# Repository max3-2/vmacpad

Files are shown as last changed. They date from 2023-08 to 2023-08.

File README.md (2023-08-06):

# vmacpad

A custom macro pad especially suited for FCPX and any other thing that needs
scrolling!

## ToDos from an old project

- Improve GND on PCB for controller. Not needed since it works really good but
better practice
- Improve plate manufacture or / and increase switch opening size. The current
dimensioning is ok but fairly tight.
- Do the same for the stabs, if possible add at least 1mm left / right for the
stems

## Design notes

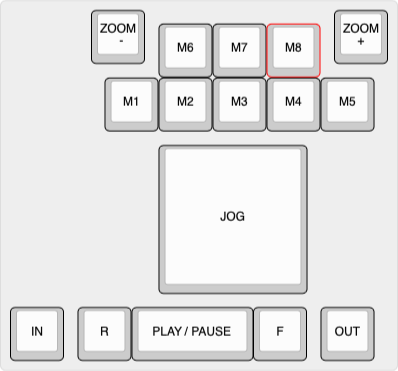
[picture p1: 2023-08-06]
layout/vmacpad.png

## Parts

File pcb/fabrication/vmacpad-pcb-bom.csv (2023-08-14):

Comment | Designator | Footprint | LCSC
22u | C1,C2 | Capacitor_SMD:C_1206_3216Metric | C2858005
10u | C10,C17 | Capacitor_SMD:C_0805_2012Metric | C88484
4.7u | C11,C13 | Capacitor_SMD:C_0402_1005Metric | C368809
10n | C14 | Capacitor_SMD:C_0402_1005Metric | C60133
10p | C15,C16 | Capacitor_SMD:C_0402_1005Metric | C115606
22n | C18,C19 | Capacitor_SMD:C_0805_2012Metric | C51574
100n | C3,C4,C5,C6,C7,C8,C9,C12 | Capacitor_SMD:C_0402_1005Metric | C77020
SM4007 | D1,D2,D4,D5,D6,D8,D9,D10,D11,D12,D13,D14,D16,D17,D18,D20 | Diode_SMD:D_SOD-123F | C64898
SMF9.0CA | DP1 | Acheron_Components:D_SOD-123_Bidirectional | C123799
ASMD1206-150 | F1 | Fuse:Fuse_1206_3216Metric | C883134
TYPE-C-31-M12_13 | J1 | Acheron_Connectors:TYPE-C-31-M-12 | C165948
60R@100MHz | L1 | Inductor_SMD:L_1206_3216Metric | C33600
5.1k | R1,R2 | Resistor_SMD:R_0805_2012Metric | C144526
10k | R3,R4 | Resistor_SMD:R_0805_2012Metric | C84376
10k | R7 | Resistor_SMD:R_0402_1005Metric | C60490
SW_BOOT | SW1 | Button_Switch_SMD:SW_SPDT_PCM12 | C431540
TPD4E05U06DQAR | U1 | Package_SON:USON-10_2.5x1.0mm_P0.5mm | C138714
TXS0101DBVR | U2 | Acheron_Components:SOT-23-6 | C132604
STM32F401RCTx | U3 | Package_QFP:LQFP-64_10x10mm_P0.5mm | C74524
AMS1117-3.3 | U4 | Package_TO_SOT_SMD:SOT-223-3_TabPin2 | C6186
16MHz | Y1 | Crystal:Crystal_SMD_3225-4Pin_3.2x2.5mm | C112972

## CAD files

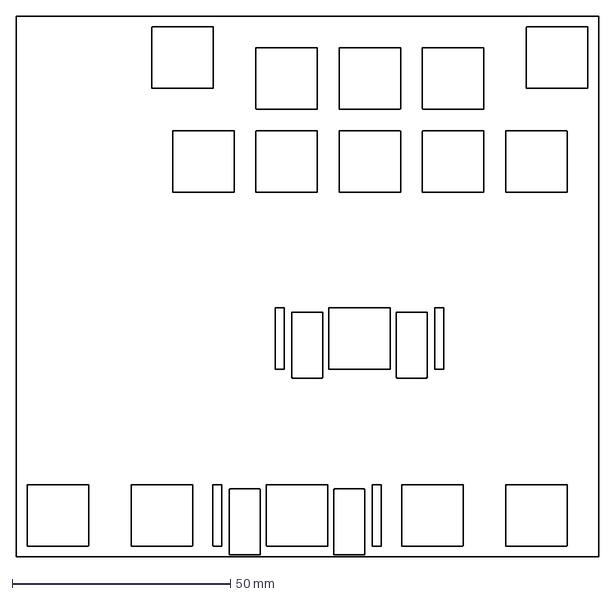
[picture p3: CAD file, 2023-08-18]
case_plate/plate.dxf
133.3 x 123.8 mm

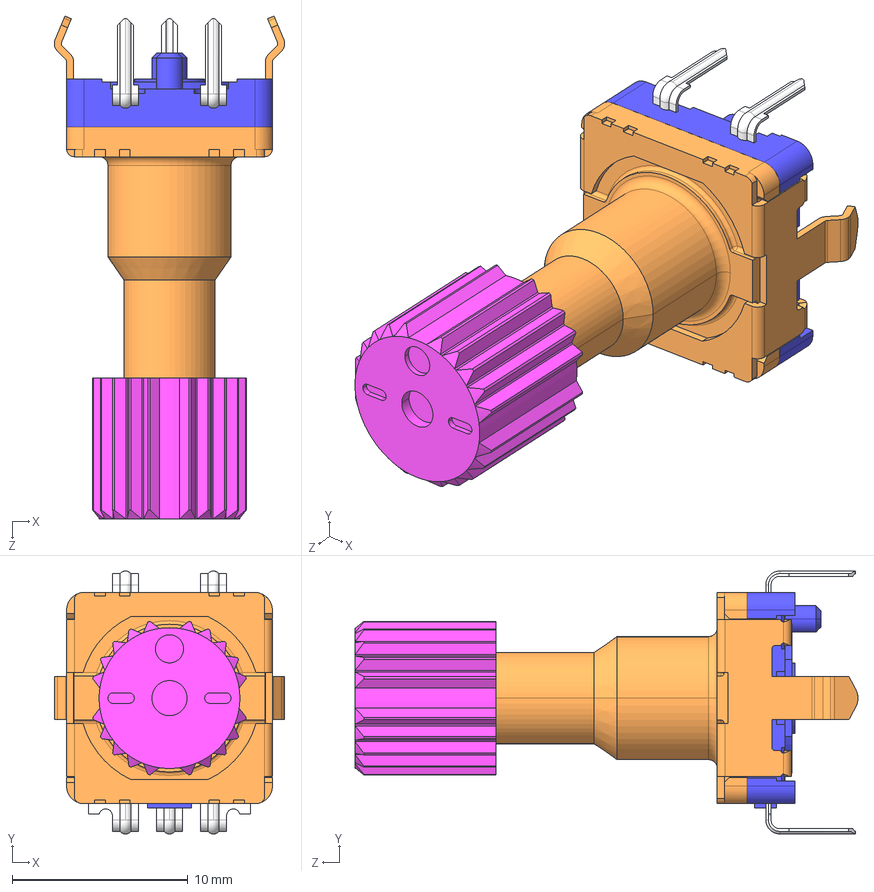
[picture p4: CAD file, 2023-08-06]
pcb/3dmodels/EC11M1565403/EC11M1565403.STEP
13.1 x 15.0 x 28.6 mm

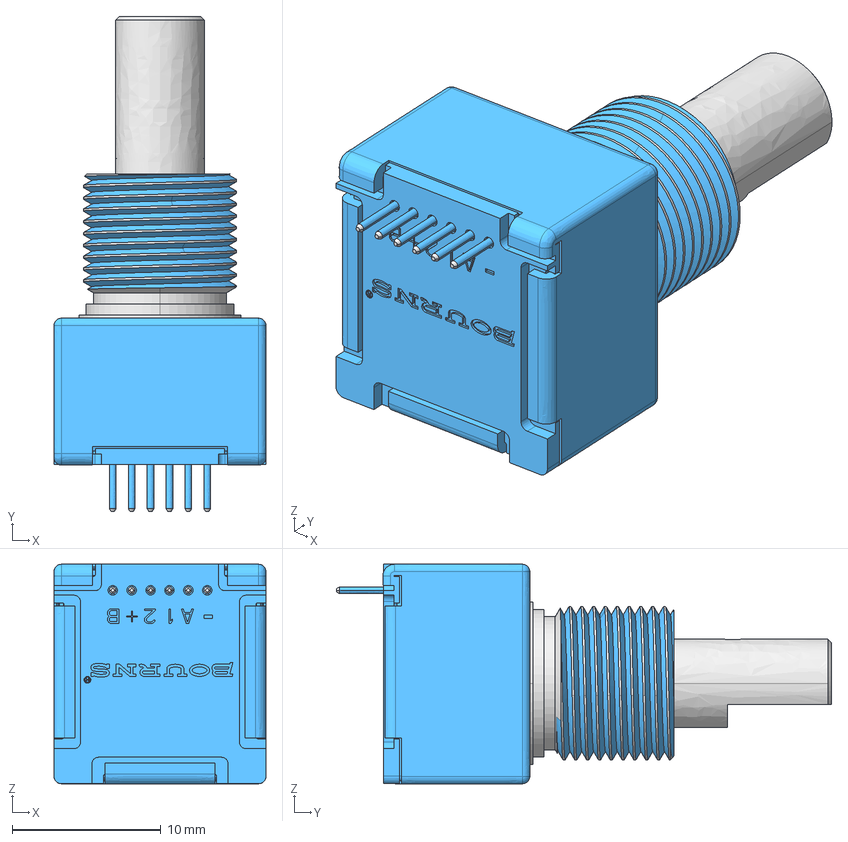
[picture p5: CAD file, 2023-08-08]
pcb/3dmodels/EM14RXD-M20-L.stp
14.2 x 33.3 x 14.8 mm

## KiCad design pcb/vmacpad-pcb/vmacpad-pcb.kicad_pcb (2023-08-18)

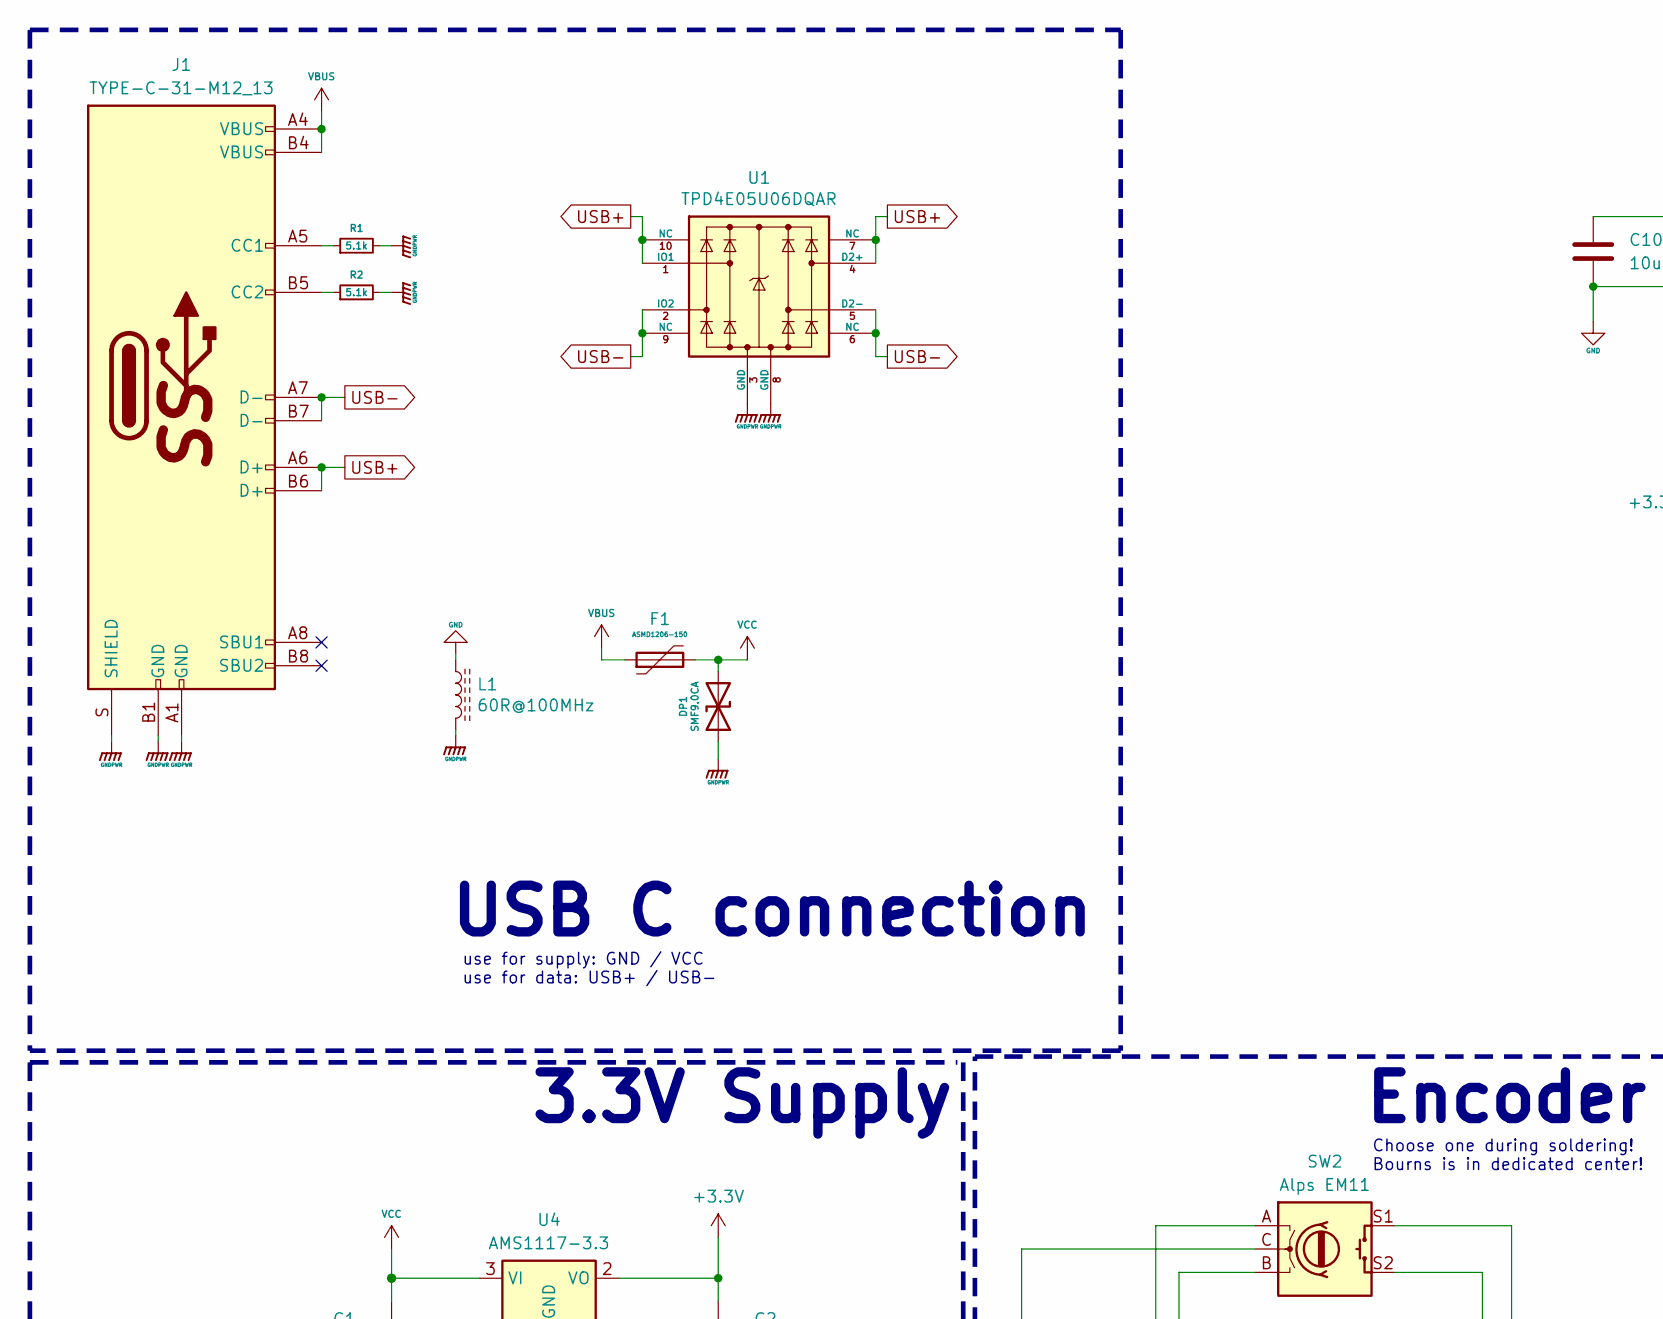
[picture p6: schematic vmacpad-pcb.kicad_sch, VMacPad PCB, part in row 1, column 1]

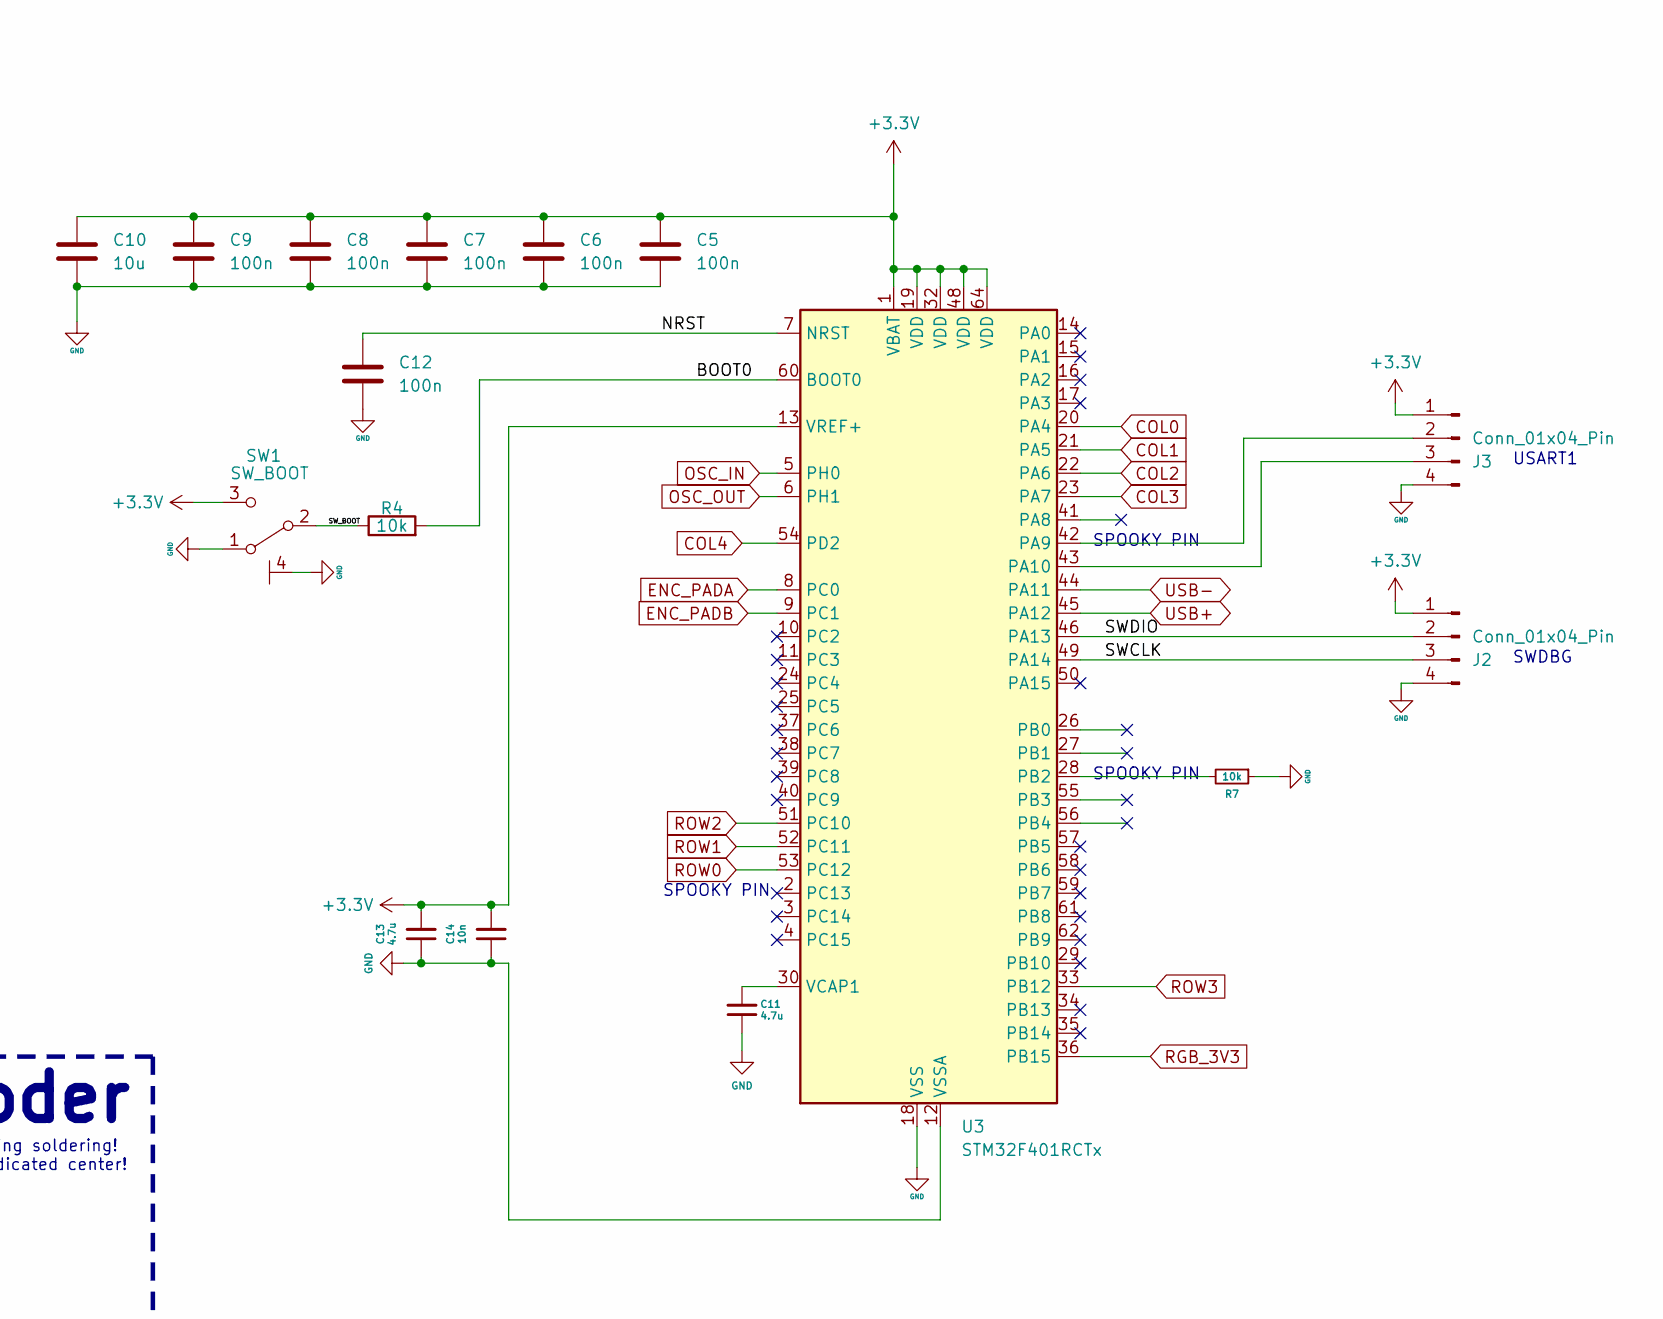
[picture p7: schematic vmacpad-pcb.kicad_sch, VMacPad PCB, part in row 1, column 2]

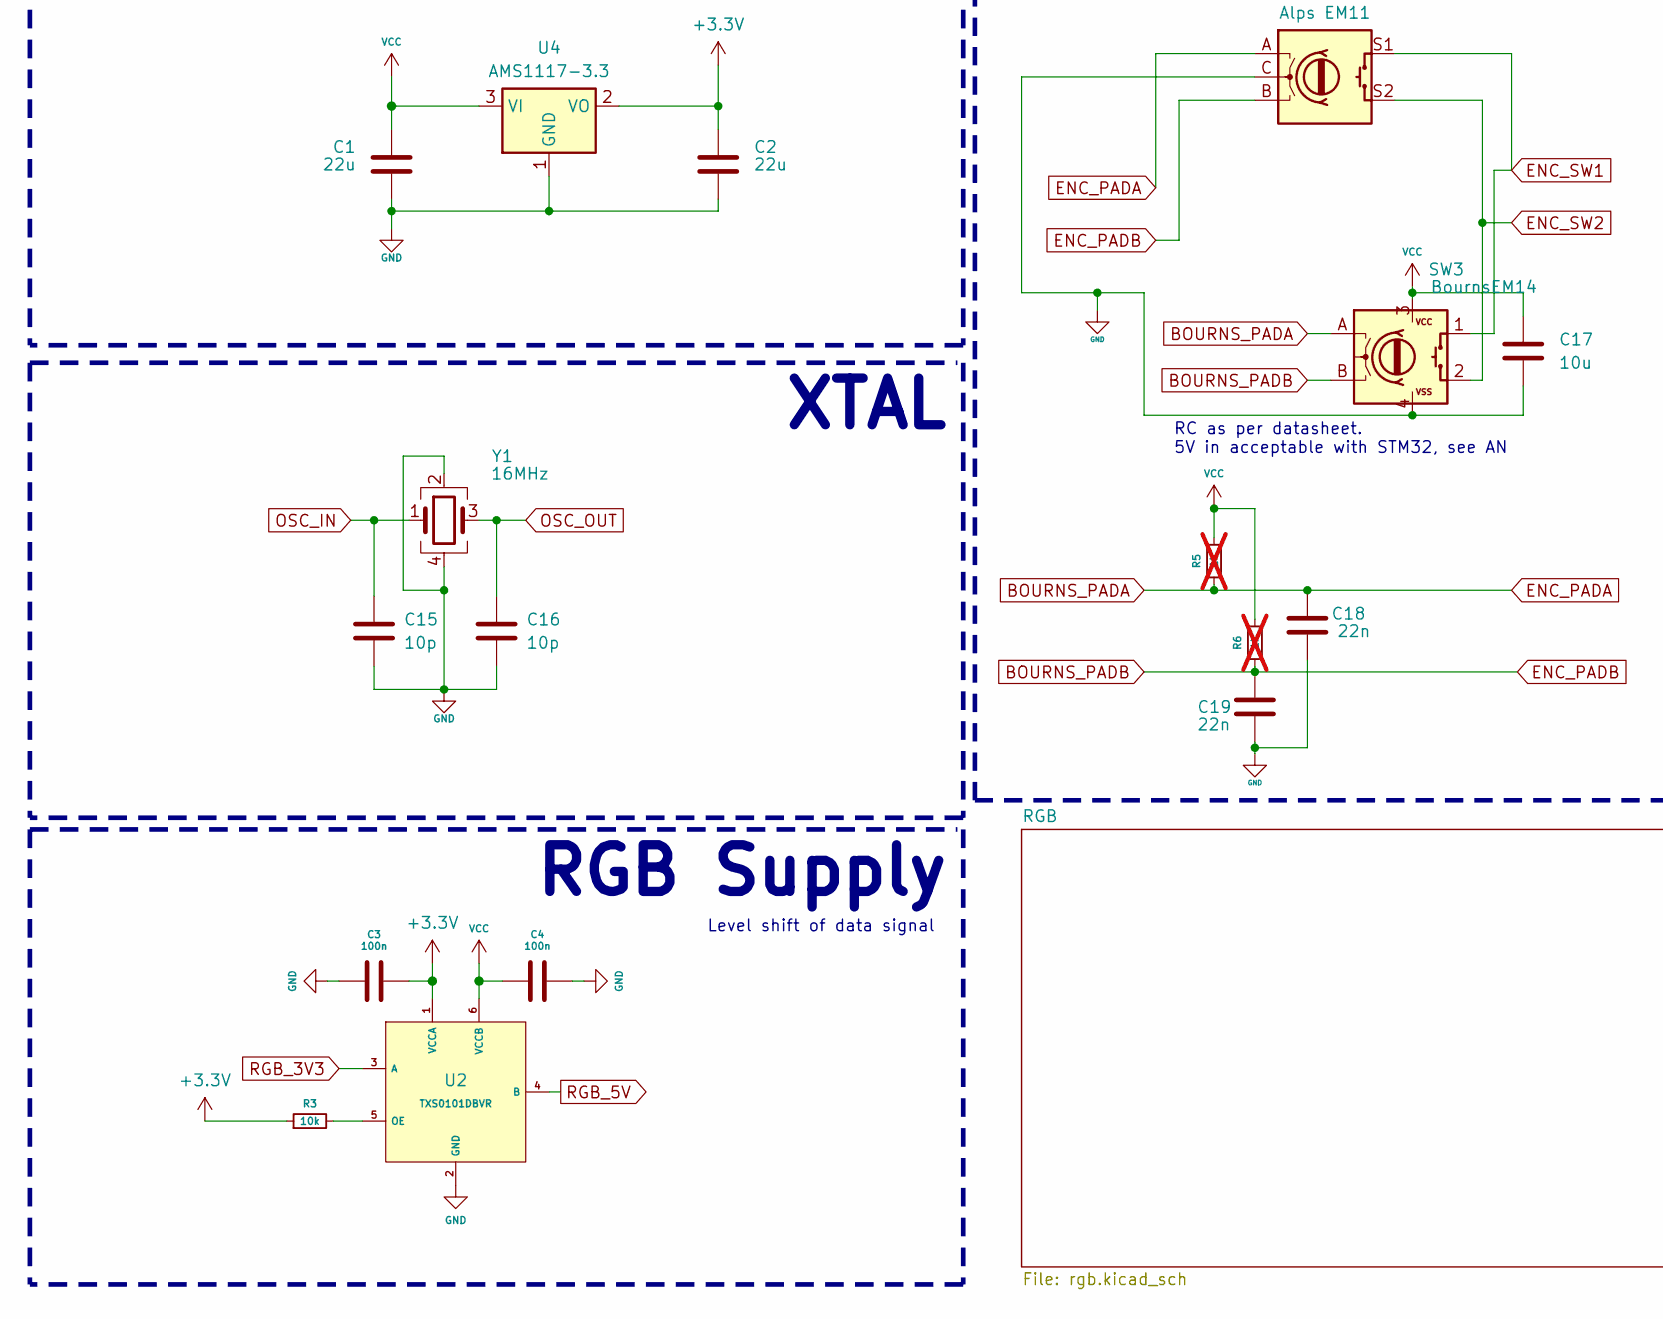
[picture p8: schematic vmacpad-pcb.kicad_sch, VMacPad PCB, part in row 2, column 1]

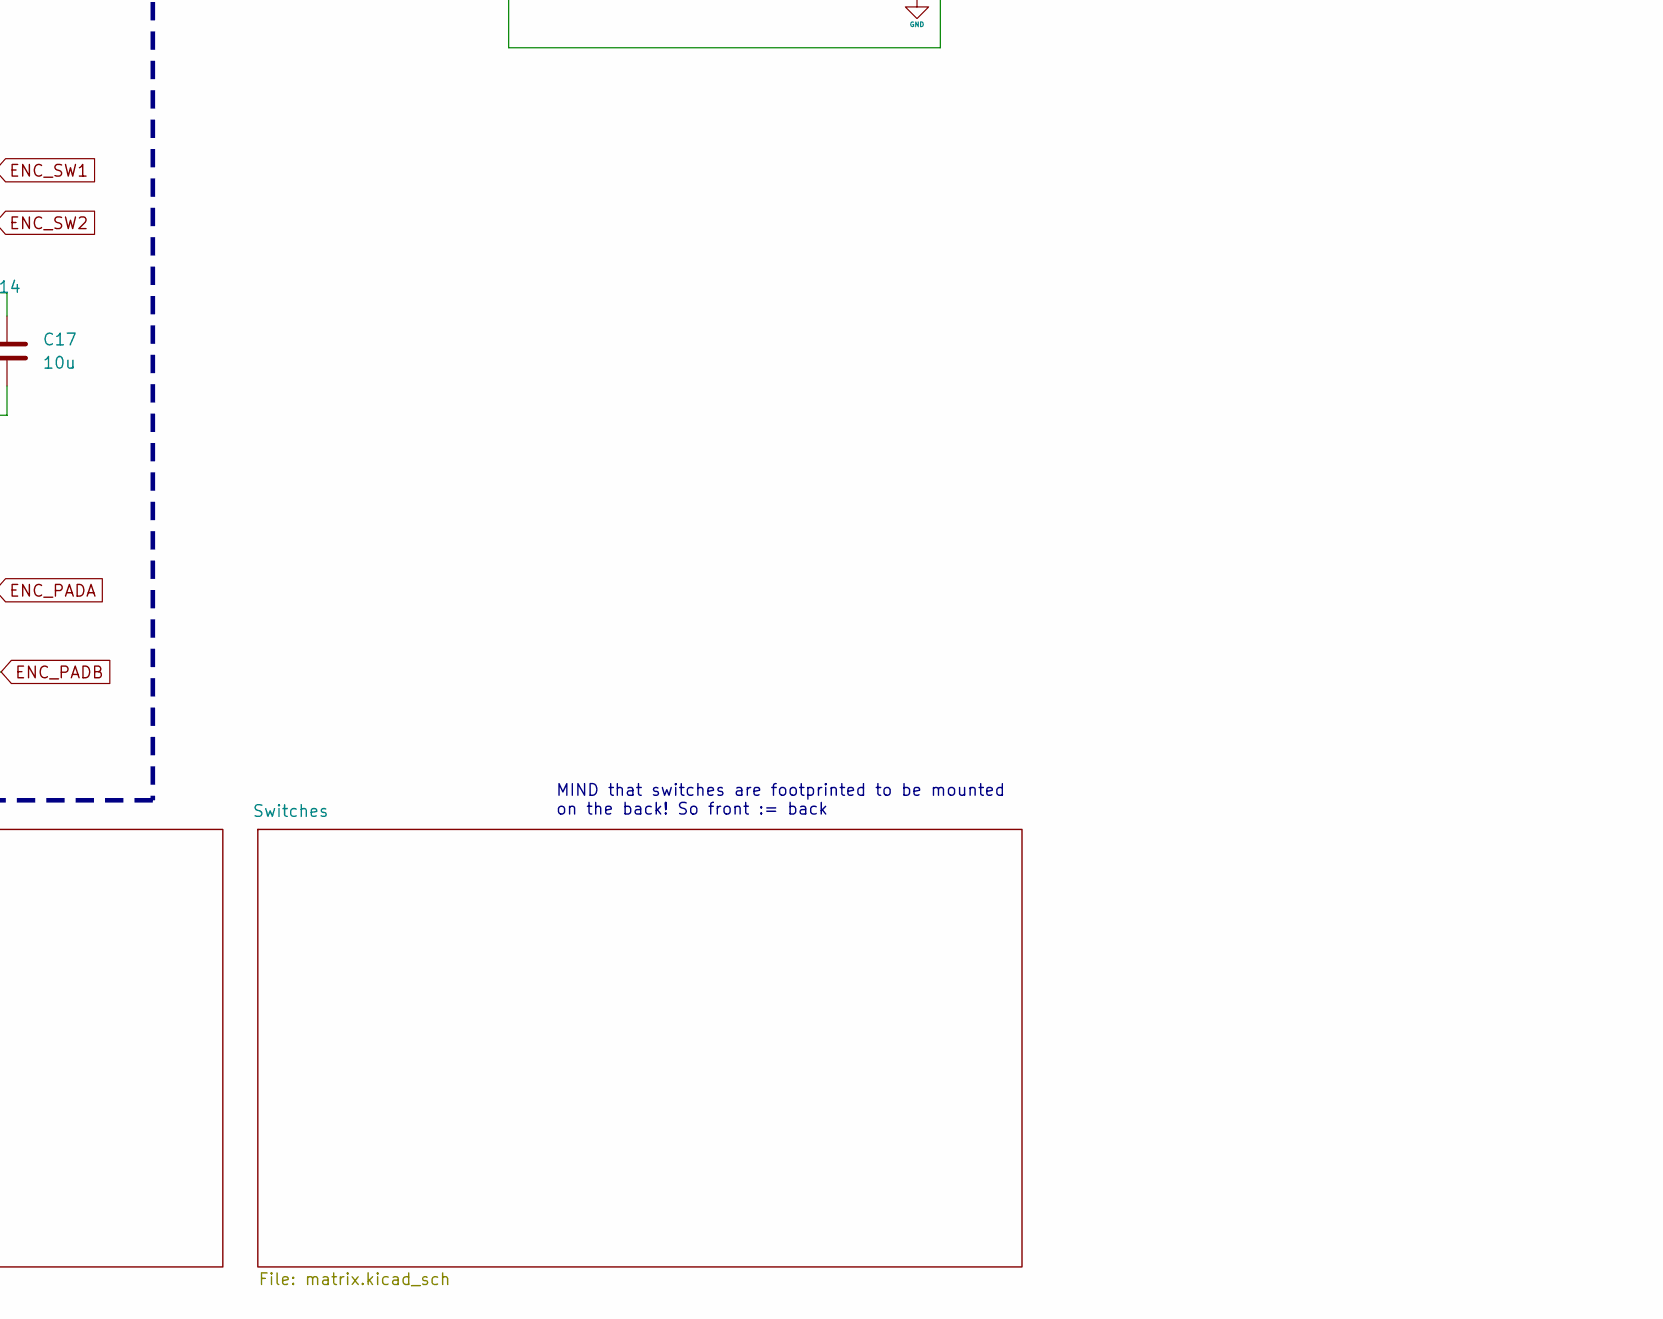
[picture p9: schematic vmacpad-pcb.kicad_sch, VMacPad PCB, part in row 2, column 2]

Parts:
C1, C2: 22u; C_1206_3216Metric; LCSC Part No C2858005
C3, C4, C5, C6, C7, C8, C9, C12: 100n; C_0402_1005Metric; LCSC Part No C77020
C10, C17: 10u; C_0805_2012Metric; LCSC Part No C88484
C11, C13: 4.7u; C_0402_1005Metric; LCSC Part No C368809
C14: 10n; C_0402_1005Metric; LCSC Part No C60133
C15, C16: 10p; C_0402_1005Metric; LCSC Part No C115606
C18, C19: 22n; C_0805_2012Metric; LCSC Part No C51574
DP1: SMF9.0CA; D_SOD-123_Bidirectional; Manufacturer Part No SMF9.0CA; LCSC Part No C123799
F1: ASMD1206-150; Fuse_1206_3216Metric; Manufacturer Part No ASMD1206-150; LCSC Part No C883134
J1: TYPE-C-31-M12_13; TYPE-C-31-M-12; Manufacturer Part No TYPE-C-31-M-12; LCSC Part No C165948
J2, J3: Conn_01x04_Pin; PinHeader_1x04_P2.54mm_Vertical
L1: 60R@100MHz; L_1206_3216Metric; Manufacturer Part No MLB3216-600P4A(f); LCSC Part No C33600
R1, R2: 5.1k; R_0805_2012Metric; LCSC Part No C144526
R3, R4: 10k; R_0805_2012Metric; LCSC Part No C84376
R5, R6: 1k; R_0805_2012Metric; LCSC Part No C115316; not fitted
R7: 10k; R_0402_1005Metric; LCSC Part No C60490
SW1: SW_BOOT; SW_SPDT_PCM12; LCSC Part No C431540
SW2: Alps EM11; RotaryEncoder_Alps_EC11E-Switch_Vertical_H20mm
SW3: BournsEM14
U1: TPD4E05U06DQAR; USON-10_2.5x1.0mm_P0.5mm; Manufacturer Part No TPD4E05U06DQAR; LCSC Part No C138714
U2: TXS0101DBVR; SOT-23-6; Manufacturer Part Number TXS0101DBVR; LCSC Part No C132604
U3: STM32F401RCTx; LQFP-64_10x10mm_P0.5mm; LCSC Part No C74524
U4: AMS1117-3.3; SOT-223-3_TabPin2; LCSC Part No C6186
Y1: 16MHz; Crystal_SMD_3225-4Pin_3.2x2.5mm; LCSC Part No C112972

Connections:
+3.3V: C2.1, C3.2, C5.1, C6.1, C7.1, C8.1, C9.1, C10.1, C13.2, C14.2, J2.1, J3.1, R3.1, SW1.3 (C), U2.1 (VCCA), U3.1 (VBAT), U3.13 (VREF+), U3.19 (VDD), U3.32 (VDD), U3.48 (VDD), U3.64 (VDD), U4.2 (VO)
/BOOT0: R4.2, U3.60 (BOOT0)
/NRST: C12.1, U3.7 (NRST)
/SWCLK: J2.3, U3.49 (PA14)
/SWDIO: J2.2, U3.46 (PA13)
/SW_BOOT: R4.1, SW1.2 (B)
BOURNS_PADA: C18.1, R5.1, SW2.A, SW3.A, U3.8 (PC0)
BOURNS_PADB: C19.1, R6.1, SW2.B, SW3.B, U3.9 (PC1)
COL0: U3.20 (PA4); also elsewhere on the board
COL1: U3.21 (PA5); also elsewhere on the board
COL2: SW2.S2, SW3.2, U3.22 (PA6); also elsewhere on the board
COL3: U3.23 (PA7); also elsewhere on the board
COL4: U3.54 (PD2); also elsewhere on the board
ENC_SW1: SW2.S1, SW3.1; also elsewhere on the board
GND: C1.2, C2.2, C3.1, C4.2, C5.2, C6.2, C7.2, C8.2, C9.2, C10.2, C11.1, C12.2, C13.1, C14.1, C15.2, C16.2, C17.2, C18.2, C19.2, J2.4, J3.4, L1.1, R7.1, SW1.1 (A), SW1.4 (Fix), SW2.C, SW3.4 (VSS), U2.2 (GND), U3.12 (VSSA), U3.18 (VSS), U3.31 (VSS), U3.47 (VSS), U3.63 (VSS), U4.1 (GND), Y1.2, Y1.4; also elsewhere on the board
GNDPWR: DP1.1 (A1), J1.A1 (GND), J1.B1 (GND), J1.S (SHIELD), L1.2, R1.2, R2.2, U1.3 (GND), U1.8 (GND)
unnamed: J1.A5 (CC1), R1.1
unnamed: J1.B5 (CC2), R2.1
unnamed: J3.2, U3.42 (PA9)
unnamed: J3.3, U3.43 (PA10)
unnamed: R3.2, U2.5 (OE)
unnamed: R7.2, U3.28 (PB2)
unnamed: C11.2, U3.30 (VCAP1)
OSC_IN: C15.1, U3.5 (PH0), Y1.1
OSC_OUT: C16.1, U3.6 (PH1), Y1.3
RGB_3V3: U2.3 (A), U3.36 (PB15)
RGB_5V: U2.4 (B); also elsewhere on the board
ROW0: U3.53 (PC12); also elsewhere on the board
ROW1: U3.52 (PC11); also elsewhere on the board
ROW2: U3.51 (PC10); also elsewhere on the board
ROW3: U3.33 (PB12); also elsewhere on the board
USB+: J1.A6 (D+), J1.B6 (D+), U1.1 (IO1), U1.4 (D2+), U1.7 (NC), U1.10 (NC), U3.45 (PA12)
USB-: J1.A7 (D-), J1.B7 (D-), U1.2 (IO2), U1.5 (D2-), U1.6 (NC), U1.9 (NC), U3.44 (PA11)
VBUS: F1.1, J1.A4 (VBUS), J1.B4 (VBUS)
VCC: C1.1, C4.1, C17.1, DP1.2 (A2), F1.2, R5.2, R6.2, SW3.3 (VCC), U2.6 (VCCB), U4.3 (VI); also elsewhere on the board

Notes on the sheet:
use for supply: GND / VCC use for data: USB+ / USB-
SWDBG
USART1
XTAL
Level shift of data signal
Choose one during soldering! Bourns is in dedicated center!
RGB Supply
RC as per datasheet. 5V in acceptable with STM32, see AN
Encoder
SPOOKY PIN
USB C connection
MIND that switches are footprinted to be mounted on the back! So front := back
3.3V Supply

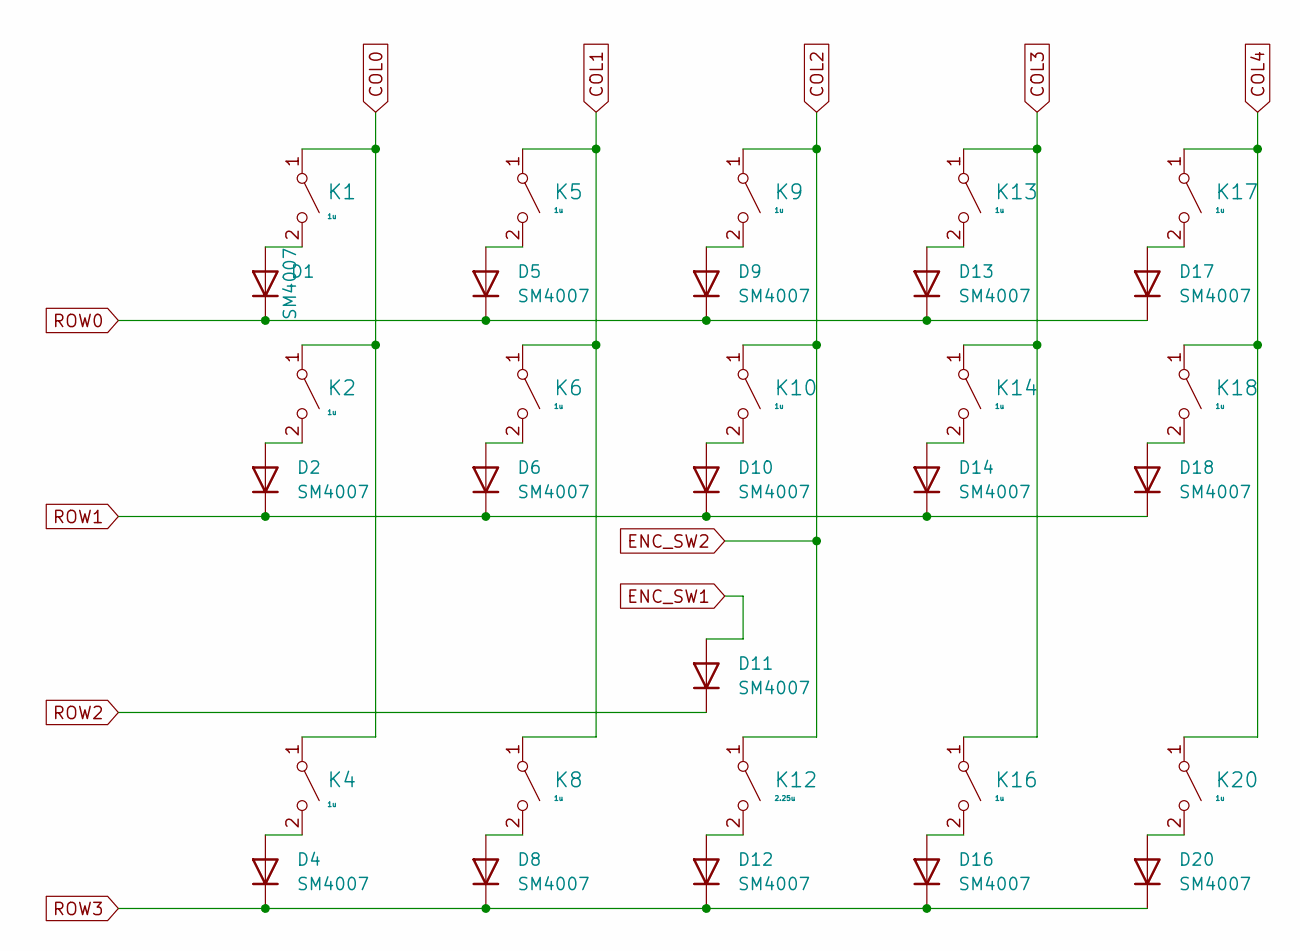
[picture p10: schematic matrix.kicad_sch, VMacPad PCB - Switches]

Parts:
D1, D2, D4, D5, D6, D8, D9, D10, D11, D12, D13, D14, D16, D17, D18, D20: SM4007; D_SOD-123F; LCSC Part No C64898
K1, K2, K4, K5, K6, K8, K9, K10, K13, K14, K16, K17, K18, K20: 1u; MX100H; LCSC Part No C5156480
K12: 2.25u; MX225HR; LCSC Part No C5156480

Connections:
COL0: K1.1 (A), K2.1 (A), K4.1 (A); also elsewhere on the board
COL1: K5.1 (A), K6.1 (A), K8.1 (A); also elsewhere on the board
COL2: K9.1 (A), K10.1 (A), K12.1 (A); also elsewhere on the board
COL3: K13.1 (A), K14.1 (A), K16.1 (A); also elsewhere on the board
COL4: K17.1 (A), K18.1 (A), K20.1 (A); also elsewhere on the board
ENC_SW1: D11.2 (A); also elsewhere on the board
unnamed: D1.2 (A), K1.2 (B)
unnamed: D2.2 (A), K2.2 (B)
unnamed: D4.2 (A), K4.2 (B)
unnamed: D5.2 (A), K5.2 (B)
unnamed: D6.2 (A), K6.2 (B)
unnamed: D8.2 (A), K8.2 (B)
unnamed: D9.2 (A), K9.2 (B)
unnamed: D10.2 (A), K10.2 (B)
unnamed: D12.2 (A), K12.2 (B)
unnamed: D13.2 (A), K13.2 (B)
unnamed: D14.2 (A), K14.2 (B)
unnamed: D16.2 (A), K16.2 (B)
unnamed: D17.2 (A), K17.2 (B)
unnamed: D18.2 (A), K18.2 (B)
unnamed: D20.2 (A), K20.2 (B)
ROW0: D1.1 (K), D5.1 (K), D9.1 (K), D13.1 (K), D17.1 (K); also elsewhere on the board
ROW1: D2.1 (K), D6.1 (K), D10.1 (K), D14.1 (K), D18.1 (K); also elsewhere on the board
ROW2: D11.1 (K); also elsewhere on the board
ROW3: D4.1 (K), D8.1 (K), D12.1 (K), D16.1 (K), D20.1 (K); also elsewhere on the board

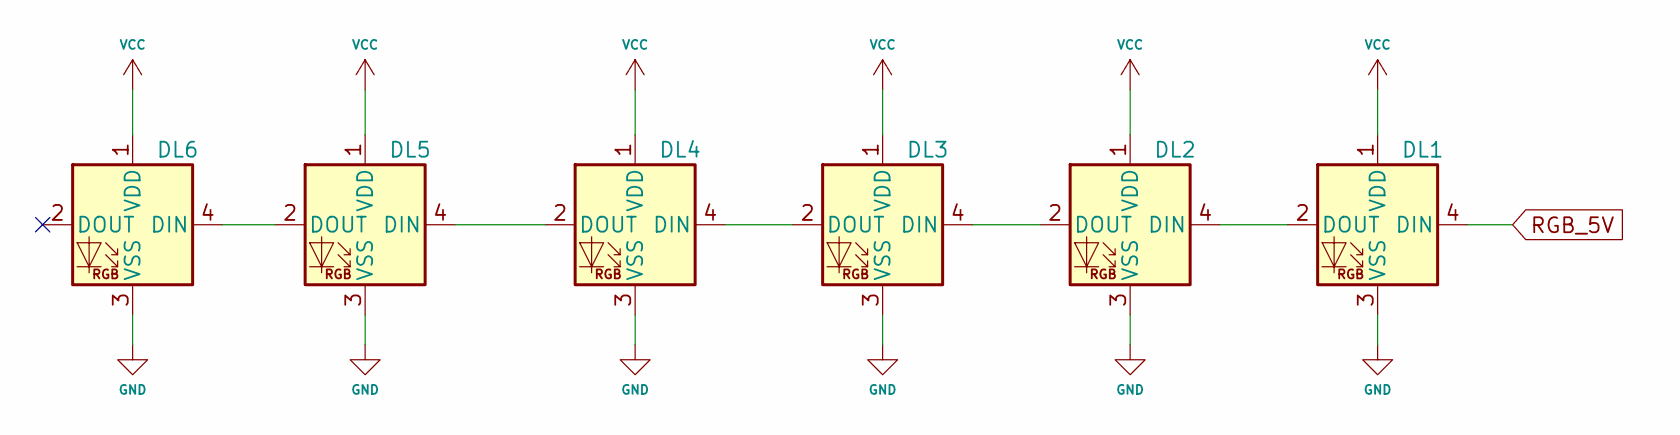
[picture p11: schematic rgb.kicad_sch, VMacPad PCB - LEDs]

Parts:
DL1, DL2, DL3, DL4, DL5, DL6: WS2812B; LED_WS2812B_PLCC4_5.0x5.0mm_P3.2mm; LCSC Part No C2874885

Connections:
GND: DL1.3 (VSS), DL2.3 (VSS), DL3.3 (VSS), DL4.3 (VSS), DL5.3 (VSS), DL6.3 (VSS); also elsewhere on the board
unnamed: DL1.2 (DOUT), DL2.4 (DIN)
unnamed: DL2.2 (DOUT), DL3.4 (DIN)
unnamed: DL3.2 (DOUT), DL4.4 (DIN)
unnamed: DL4.2 (DOUT), DL5.4 (DIN)
unnamed: DL5.2 (DOUT), DL6.4 (DIN)
RGB_5V: DL1.4 (DIN); also elsewhere on the board
VCC: DL1.1 (VDD), DL2.1 (VDD), DL3.1 (VDD), DL4.1 (VDD), DL5.1 (VDD), DL6.1 (VDD); also elsewhere on the board

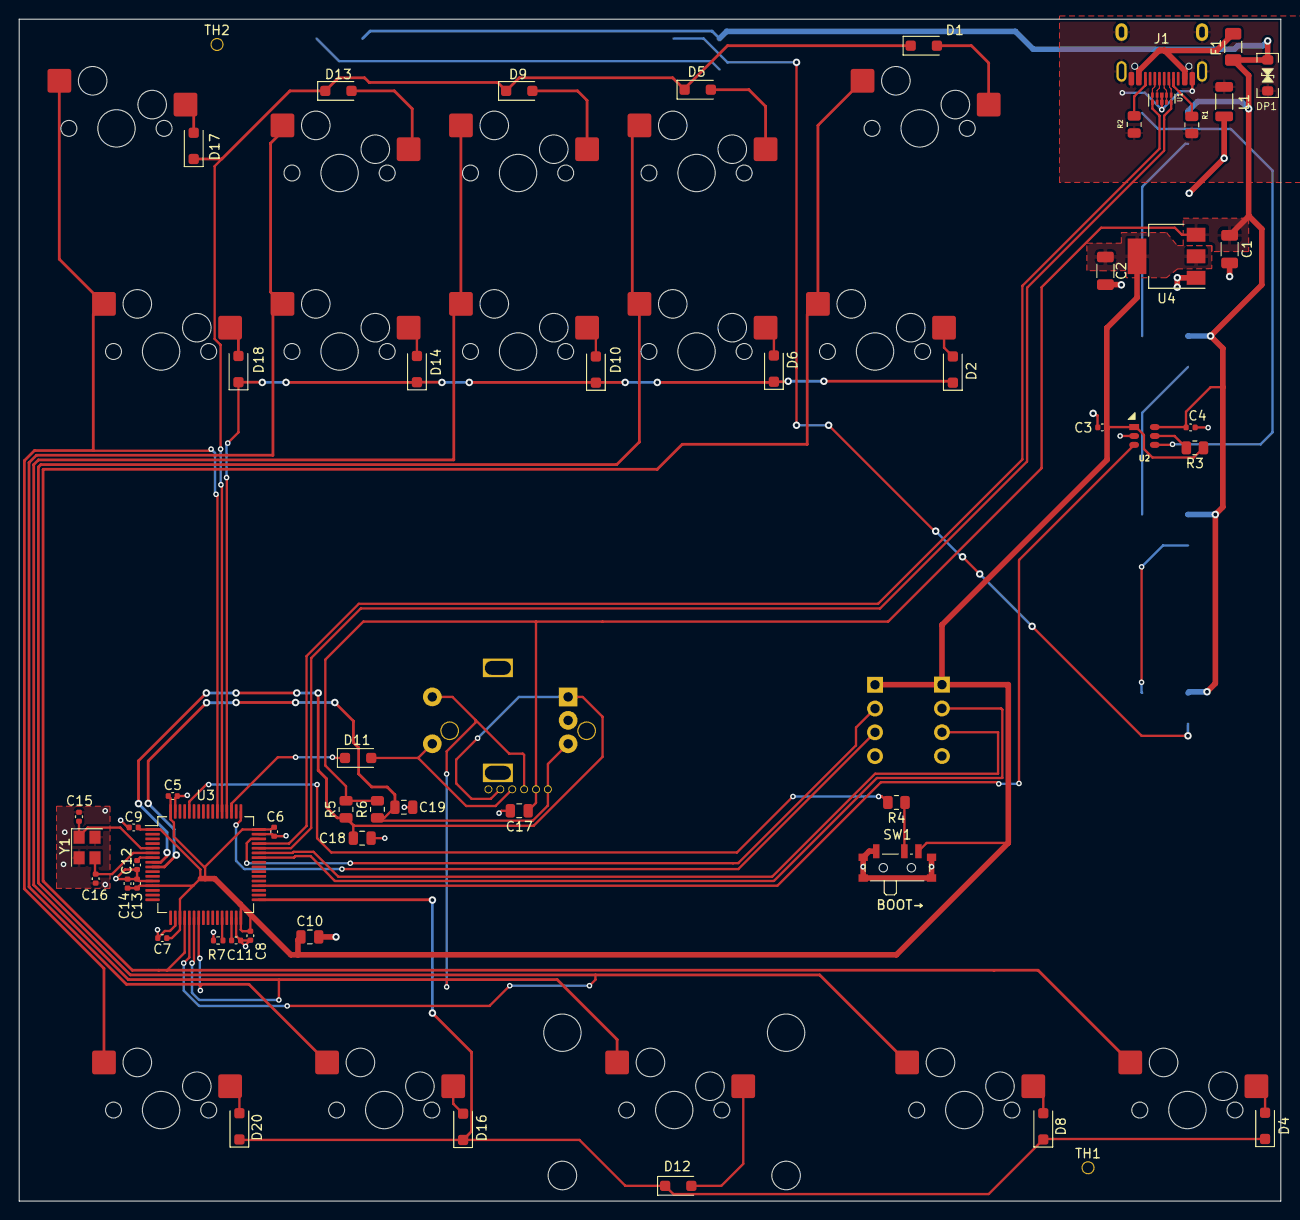
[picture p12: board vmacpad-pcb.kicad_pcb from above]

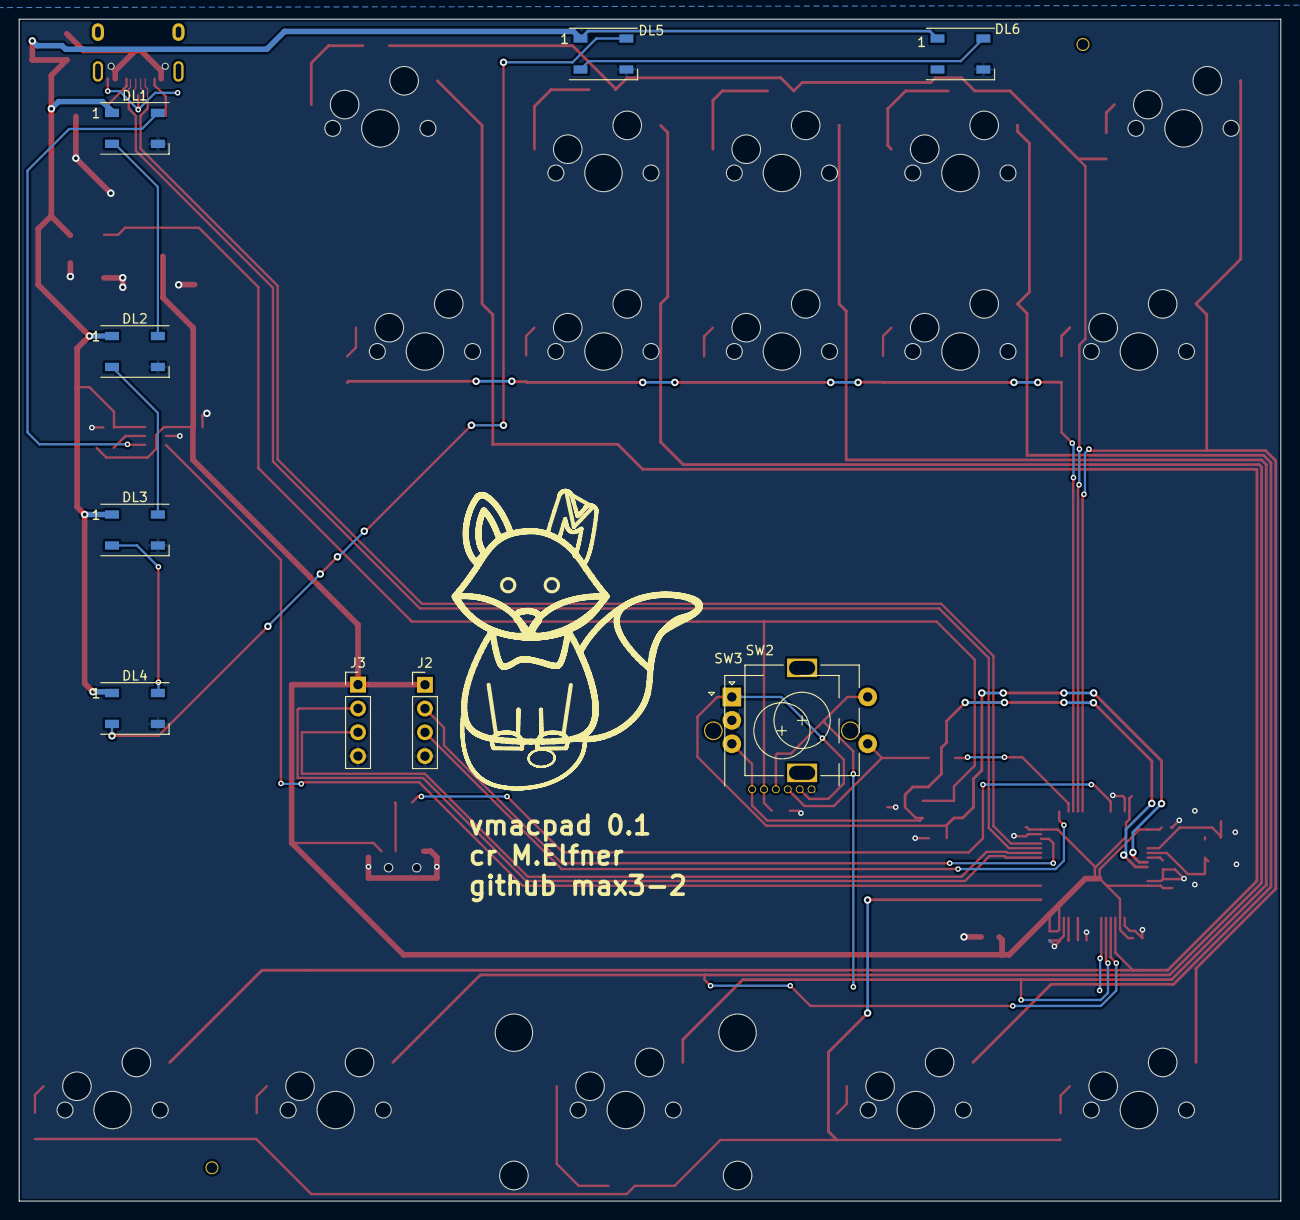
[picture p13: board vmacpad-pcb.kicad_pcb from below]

Board: 2 copper layers, 134.7 x 126.1 mm, 79 parts (10 on the bottom side), 55 nets.

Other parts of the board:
TH1, TH2: jlcpcb_tooling

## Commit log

2023-08-06 Encoder 1 3d model
    [EC11M1565403.STEP]
2023-08-06 PCB Initial work
    [matrix.kicad_sch, rgb.kicad_sch, vmacpad-pcb.kicad_pcb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]
2023-08-08 Creating the PCB and additional parts
    [EM14RXD-M20-L.stp, matrix.kicad_sch, rgb.kicad_sch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]
2023-08-12 Schematic Rev 1 done
    [matrix.kicad_sch, rgb.kicad_sch, vmacpad-pcb.kicad_pcb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]
2023-08-13 Finalizing PCB
    [matrix.kicad_sch, vmacpad-pcb.kicad_pcb, vmacpad-pcb.kicad_sch]
2023-08-14 Final tweaks
    [vmacpad-pcb.kicad_pcb]
2023-08-14 Add tooling holes
    [vmacpad-pcb.kicad_pcb]
2023-08-14 Fix properties
    [matrix.kicad_sch, rgb.kicad_sch, vmacpad-pcb.kicad_pcb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]
2023-08-14 Fixes to part numbers and production
    [matrix.kicad_sch, rgb.kicad_sch, vmacpad-pcb.kicad_pcb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]
2023-08-14 Added initial FAB
    [vmacpad-pcb-all-pos_edited.csv, vmacpad-pcb-bom.csv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]
2023-08-16 Fix power trace width
    [vmacpad-pcb.kicad_pcb]
2023-08-18 Add plate and pcb 3d, fix models and export
    [plate.dxf, vmacpad-pcb.kicad_pcb]
